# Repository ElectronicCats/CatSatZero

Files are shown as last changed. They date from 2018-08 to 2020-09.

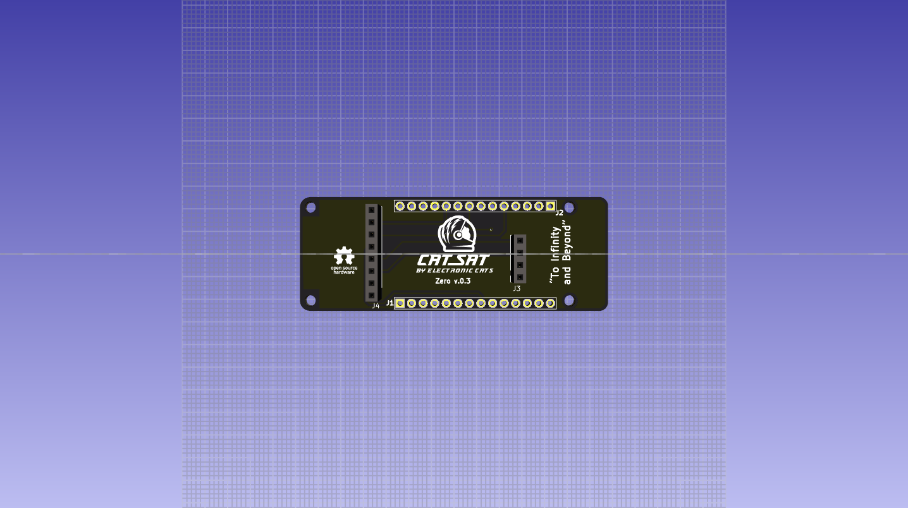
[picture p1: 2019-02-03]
CatSatShield/front.png

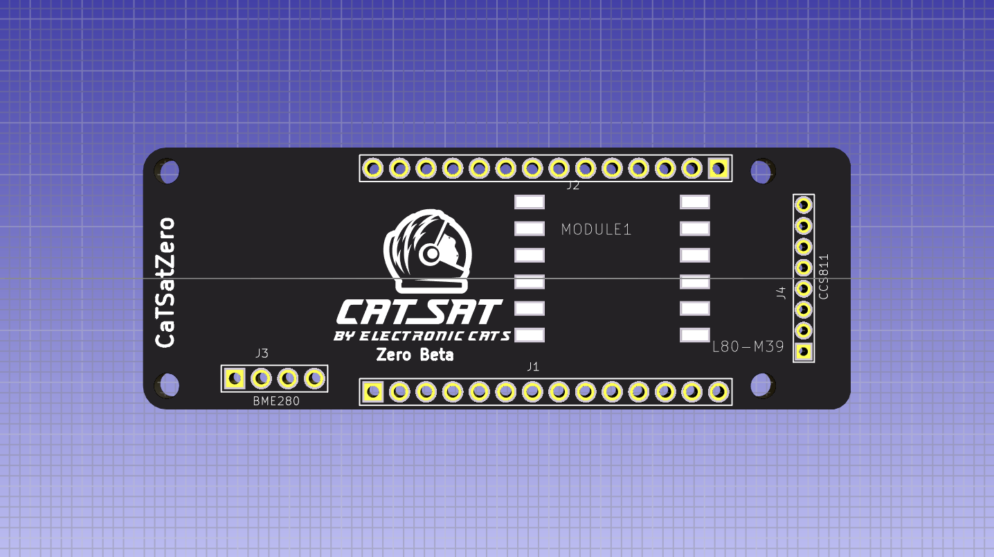
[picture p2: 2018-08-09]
CatSatShield/catsatzero.png

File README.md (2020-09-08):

# CaTSatZero

Kit CatSat Zero Education

Manual and more information in our [Wiki](https://github.com/ElectronicCats/CatSatZero/wiki)

Electronic Cats invests time and resources providing this open source design, please support Electronic Cats and open-source hardware by purchasing products from Electronic Cats!

Designed by Electronic Cats.

<a href="https://electroniccats.com">
  
</a>

## License

OpenSourceLicense

Firmware released under an GNU AGPL v3.0 license. See the LICENSE file for more information.

Hardware released under an CERN Open Hardware Licence v1.2. See the LICENSE_HARDWARE file for more information.

Electronic Cats is a registered trademark, please do not use if you sell these PCBs.

15 April 2018

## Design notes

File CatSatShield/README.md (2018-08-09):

# MKR Shield Template

Template of shield family MKR Arduino in KiCad 5

Mkrshield

Electronic Cats invests time and resources providing this open source design, please support Electronic Cats and open-source hardware by purchasing products from Electronic Cats!

Designed by Electronic Cats.

Hardware released under an CERN Open Hardware Licence v1.2. See the LICENSE_HARDWARE file for more information.

Electronic Cats is a registered trademark, please do not use if you sell these PCBs.

July 2018

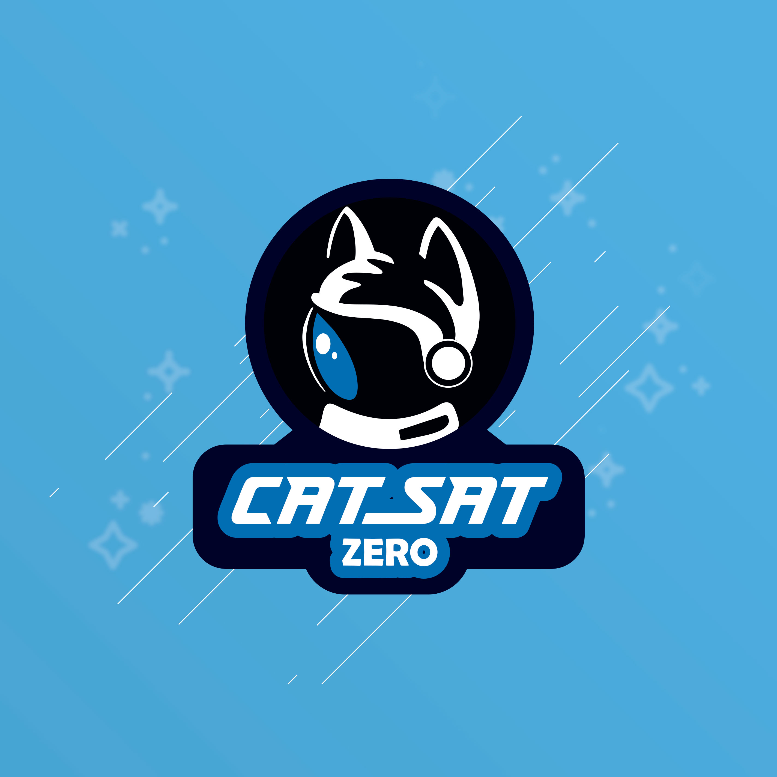
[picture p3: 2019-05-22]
catsatzero.jpg

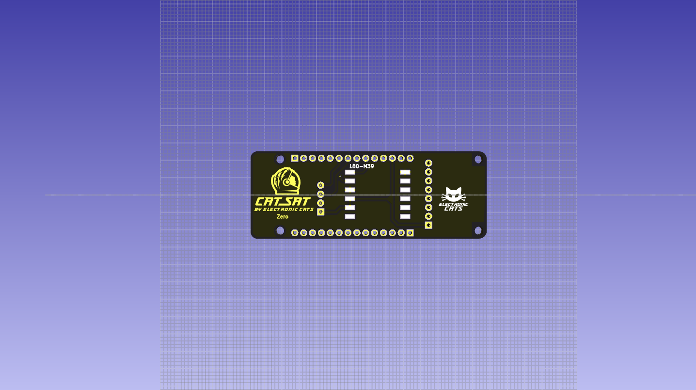
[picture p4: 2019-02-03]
CatSatShield/back.png

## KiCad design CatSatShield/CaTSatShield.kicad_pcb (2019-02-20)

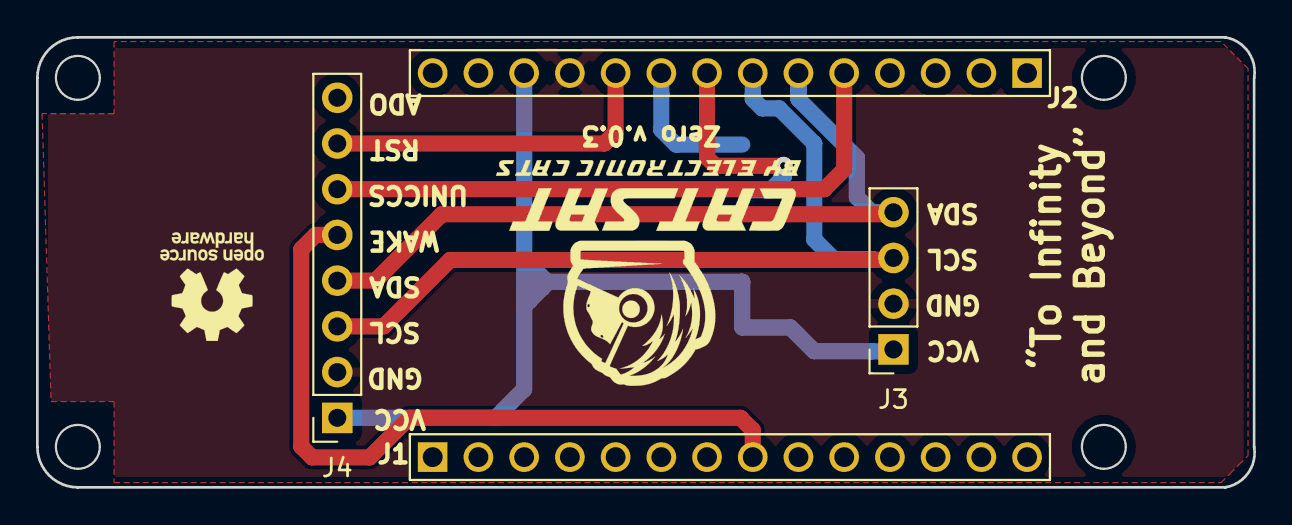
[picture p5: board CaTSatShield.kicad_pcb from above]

Board: 2 copper layers, 67.6 x 25.0 mm, 14 parts (0 on the bottom side), 9 nets.

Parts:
@HOLE0, @HOLE1, @HOLE2, @HOLE3: (no value)
FRAME1: Page 1; FRAME
J1, J2: 61301411121
J3: BME280; PinSocket_1x04_P2.54mm_Vertical
J4: CCS811; PinSocket_1x08_P2.54mm_Vertical
MODULE1: L80-M39; QUECTEL_L80-M39
U$5, U$6, U$7, U$8: MH_RND_F_2.2MM_NM

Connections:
+3V3: J2.12, J3.1, J4.1, MODULE1.4, MODULE1.5
/10-INTCCS: J2.5, J4.6
/RESET: J2.10, J4.7
/RX: J2.8, MODULE1.2
/SCL: J2.7, J3.3, J4.3
/SDA: J2.6, J3.4, J4.4
/TX: J2.9, MODULE1.1
/WAKEA6: J1.8, J4.5
GND: J2.11, J3.2, J4.2, MODULE1.3, MODULE1.12

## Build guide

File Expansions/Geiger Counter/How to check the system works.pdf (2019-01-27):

### How to check the system works

step1）Power on the system, use the USB cable connect the system to computer USB Port
step 2）you could hear the beep and see the led flash
how the Geiger Muller Tube works：

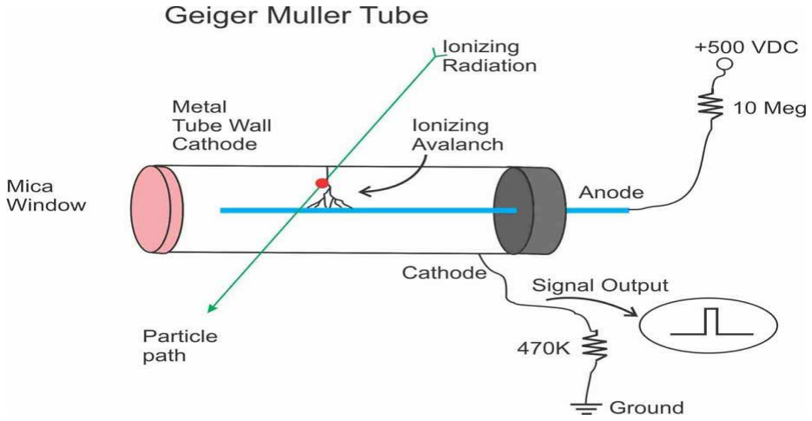
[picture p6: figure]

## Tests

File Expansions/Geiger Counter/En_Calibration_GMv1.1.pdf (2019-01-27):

Calibration:
(the board is calibrated before shipping. If you want to calibrate it again please follow the instruction of calibration)
You need to calibrate the high voltage BEFORE installing Geiger tubes. The HV calibration steps are:
1. Trim R100 potentiometer to approximately 50 ohm when kit power is off.
2. Connect positive Tube Clip to pins (J4) with a jumper wrie.
3. Connect multimeter black probe to any GND point
4. Connect multimeter probe after J2 point

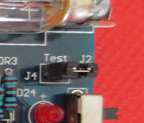
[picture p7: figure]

5. Set your multimeter on 200V DC range.
6. Power up the device (PCB washed and IC555 installed).
7. Adjust voltage with R100 to 6.5V if you use 1M multimeter or adjust the voltage 57V if you use 10M multimeter .Use formula:Vout=Vread*((60M+Rvoltmeter)/Rvoltmeter.)
R100 is the 100Ohm potentiometer.

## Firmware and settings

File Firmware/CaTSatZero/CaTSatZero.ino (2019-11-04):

/************************************************************
  SPANISH
  CatSat Zero
  CatSat Zero - Satelite en Lata Educativo
  Andres Sabas @ Electronic Cats
  Eduardo Contreras @ Electronic Cats
  Original Creation Date: Ago 14, 2018
  https://github.com/ElectronicsCats/CatSatZero/

  Este ejemplos demuestra el funcionamiento basico de los sensores y funcionalidad
  basica del CatSatZero Kit Educativo
  http://electroniccats.com

  Especificaciones del entorno de Desarrollo:
  IDE: Arduino 1.8.4
  Plataforma de Hardware:
  Kit CanSat
  - Arduino MKR1300
  - BMP280
  - CCS811
  - GPS L80


  Este código es beerware si tu me ves ( o cualquier otro miembro de Electronic Cats)
  a nivel local, y tu has encontrado nuestro código útil ,
  por favor comprar una ronda de cervezas!

  Distribuido como; no se da ninguna garantía.
************************************************************/

/************************************************************
  ENGLISH
  CatSat Zero
  CatSat - Satelite en Lata Educativo
  Andres Sabas @ Electronic Cats
  Eduardo Contreras @ Electronic Cats
  Original Creation Date: Agu 14, 2018
  https://github.com/ElectronicsCats/CatSatZero/

  This example demonstrates how to use CatSat

  Development environment specifics:
  IDE: Arduino 1.8.4
  Hardware Platform:
  Kit CanSat
  - Arduino MKR 1300
  - BMP280
  - CCS811
  - GPS L80

  This code is beerware; if you see me (or any other Electronic Cats
  member) at the local, and you've found our code helpful,
  please buy us a round!

  Distributed as-is; no warranty is given.

  Library Arduino LoRa
  https://github.com/sandeepmistry/arduino-LoRa

*/
//Uncomment for debug
//#define DEBUG
//#define DEBUG2

#include <SPI.h>
#include <LoRa.h>

#include <NMEAGPS.h>

#include <Wire.h>
#include <SparkFunBME280.h>

#include <Adafruit_CCS811.h>

#ifdef GEIGER
#define LOG_PERIOD 15000  //Logging period in milliseconds, recommended value 15000-60000.
#define MAX_PERIOD 60000  //Maximum logging period without modifying this sketch

#define index_conversion 151.00

unsigned long counts = 0;     //variable for GM Tube events
unsigned long cpm = 0;        //variable for CPM
unsigned int multiplier;  //variable for calculation CPM in this sketch
unsigned long previousMillis;  //variable for time measurement
float radiationValue = 0.0;

#define radationpin 4

#endif

#define CCS811_ADDR 0x5A //0x5B Alternate I2C Address

//Command activation Balloon mode
#define PMTK_SET_NMEA_886_PMTK_FR_MODE  "$PMTK886,3*2B"
// Command turn on GPRMC and GGA
#define PMTK_SET_NMEA_OUTPUT_RMCGGA "$PMTK314,0,1,0,1,0,0,0,0,0,0,0,0,0,0,0,0,0,0,0*28"

//Global sensor objects
Adafruit_CCS811 ccs;
BME280 myBME280;

static NMEAGPS gps;
static gps_fix  fix;
static uint32_t last_rx = 0UL; // The last millis() time a character was
// received from GPS.

String Todo; //String a mandar

/************************************************************
     IMPORTANTE CAMBIAR id_node DEPENDIENDO TU CANSAT
************************************************************/

String id_node = "A1";

/*******************************************************
  Selecciona un canal entre 0 y 12 este debe coincidir
  con el canal de tu satelite
 *******************************************************/
int channel = 12;

float voltage = 0;

void enviarInfo(String outgoing) {
  LoRa.beginPacket();
  char outgoingCh[Todo.length()+1];
  outgoing.toCharArray(outgoingCh,outgoing.length());
  LoRa.write((uint8_t *)outgoingCh,outgoing.length());                                     
  LoRa.endPacket();                    

#ifdef DEBUG
  SerialUSB.println("Dato enviado");
#endif
}

void gpsread(void) {
  if (fix.valid.location)
  {
    Todo += String(fix.latitude(), 6);
    Todo += ",";
    Todo += String(fix.longitude(), 6);
#ifdef DEBUG 
    SerialUSB.print("Location: ");
    SerialUSB.print(fix.latitude(), 6);
    SerialUSB.print(F(","));
    SerialUSB.print(fix.longitude(), 6);
#endif
  }
  else
  {
    Todo += "0";
    Todo += ",";
    Todo += "0";
#ifdef DEBUG
    SerialUSB.print("INVALID");
#endif
  }
#ifdef DEBUG
  SerialUSB.print("  Date/Time: ");
  if (fix.valid.date)
  {
    SerialUSB.print(fix.dateTime.month);
    SerialUSB.print("/");
    SerialUSB.print(fix.dateTime.day);
    SerialUSB.print("/");
    SerialUSB.print(fix.dateTime.year);
    SerialUSB.print(" ");
  }
  else
  {
    SerialUSB.print("INVALID ");
  }

  SerialUSB.print("");
  if (fix.valid.date)
  {
    if (fix.dateTime.hours < 10) SerialUSB.print("0");
    SerialUSB.print(fix.dateTime.hours);
    SerialUSB.print(":");
    if (fix.dateTime.minutes < 10) SerialUSB.print("0");
    SerialUSB.print(fix.dateTime.minutes);
    SerialUSB.print(":");
    if (fix.dateTime.seconds < 10) SerialUSB.print("0");
    SerialUSB.print(fix.dateTime.seconds);
    SerialUSB.print(".");
  }
  else
  {
    SerialUSB.print("INVALID ");
  }
  SerialUSB.println();
#endif

}

/*
  Activation Balloon mode:
  For high-altitude balloon purpose that the vertical movement will
  have more effect on the position calculation
*/
void ballonModeGPS() {
    if ((Serial1.available())) {
      Serial1.println(PMTK_SET_NMEA_886_PMTK_FR_MODE);
      delay(100);
      Serial1.println(PMTK_SET_NMEA_OUTPUT_RMCGGA);
      SerialUSB.println("GPS balloon mode configured");
    }
    else{
      SerialUSB.println("Error in GPS, balloon mode not configured");
      }
}

void setup() {
  SerialUSB.begin(9600);
  Serial1.begin(9600);
#ifdef DEBUG2
  while (!SerialUSB);
#endif
  SerialUSB.println();
  SerialUSB.println("Settings...");

  pinMode(LED_BUILTIN, OUTPUT);
  digitalWrite(LED_BUILTIN, LOW);

  pinMode(A6, OUTPUT); //Wakeup pin CCS811
  digitalWrite(A6, LOW); //Enable CCS811

  analogReadResolution(10);
  analogReference(AR_INTERNAL2V23); 
  
  /*****LoRa init****/
  if (!LoRa.begin(selectBand(channel))) {           
    Serial.println("LoRa init failed. Check your connections.");
    while (true);                       
  }
  LoRa.enableCrc();
  LoRa.setTxPower(20); //Set the max transmition power
  LoRa.setSpreadingFactor(10); //Change the SF to get longer distances

  /******************/

  //This begins the CCS811 sensor and prints error status of .begin()
  if (!ccs.begin(CCS811_ADDR)) {
    Serial.println("Failed to start sensor CCS811! Please check your wiring.");
    while (1);
  }
 
  Serial.println("CCS begin");
  //calibrate temperature sensor
  while (!ccs.available());
  float temp = ccs.calculateTemperature();
  ccs.setTempOffset(temp - 25.0);

  //For I2C, enable the following and disable the SPI section
  myBME280.settings.commInterface = I2C_MODE;
  myBME280.settings.I2CAddress = 0x76;

  //Initialize BME280
  //For I2C, enable the following and disable the SPI section
  myBME280.settings.commInterface = I2C_MODE;
  myBME280.settings.I2CAddress = 0x76;
  myBME280.settings.runMode = 3; //Normal mode
  myBME280.settings.tStandby = 0;
  myBME280.settings.filter = 4;
  myBME280.settings.tempOverSample = 5;
  myBME280.settings.pressOverSample = 5;
  myBME280.settings.humidOverSample = 5;

  //Calling .begin() causes the settings to be loaded
  delay(10);  //Make sure sensor had enough time to turn on. BME280 requires 2ms to start up.
  int status280 = myBME280.begin();
  
  Serial.println("BME begin");
  if (status280 != 0x60) {
    Serial.println("Could not find a valid BME280 sensor, check wiring!");
    while (1);
  }
  
  ballonModeGPS();
  
#ifdef GEIGER
  multiplier = MAX_PERIOD / LOG_PERIOD;      //calculating multiplier, depend on your log period
  attachInterrupt(digitalPinToInterrupt(radationpin), tube_impulse, FALLING); //define external interrupts
#endif

  SerialUSB.println("CaTSat Zero Ready!");
  Serial.println(F("Fw version 0.0.3"));
}

void loop() {

  Todo += id_node;  //Add id to String
  Todo += ",";

#ifdef GEIGER
  //Read Geiger Sensor
  if (millis() - previousMillis > LOG_PERIOD) {
    previousMillis = millis();
    cpm = counts * multiplier;
    radiationValue = cpm / index_conversion;
#ifdef DEBUG
    Serial.print("cpm = ");
    Serial.println(cpm, DEC);
    Serial.print("uSv/h = ");
    Serial.println(radiationValue, 4);
#endif
    counts = 0;
  }
#endif

  while (gps.available( Serial1 )) {
    last_rx = millis();
    fix = gps.read();

    printInfoSerial();

    // read the input on analog pin battery
    //NOTE: voltage max 1.18v in the pin of chip
    uint16_t sensorValue = analogRead(ADC_BATTERY);
    voltage = sensorValue*2.23/1024;
    voltage = voltage*3.05;

    gpsread();

    Serial.println(Todo);
    enviarInfo(Todo);
    for (int i = 0; i < 5; i++) {
      digitalWrite(LED_BUILTIN, HIGH);
      delay(500);
      digitalWrite(LED_BUILTIN, LOW);
      delay(500);
    }
  }

  Todo = "";
  listenForSomething();
}

void printInfoSerial()
{
  if (ccs.available()) {
    float temp = ccs.calculateTemperature();
    if (!ccs.readData()) {
#ifdef DEBUG
      Serial.print("CO2: ");
      Serial.print(ccs.geteCO2());
      Serial.print("ppm, TVOC: ");
      Serial.print(ccs.getTVOC());
#endif
      Todo += ccs.geteCO2();
      Todo += ",";
      Todo += ccs.getTVOC();
      Todo += ",";
    }
    else {
      Serial.println("ERROR!");
      while (1);
    }
  }

#ifdef DEBUG
  SerialUSB.println();
  SerialUSB.println("BME280 data:");
  SerialUSB.print(" Temperature: ");
  SerialUSB.print(myBME280.readTempC(), 2);
  SerialUSB.println(" degrees C");
#endif
  Todo += myBME280.readTempC();
  Todo += ",";

#ifdef DEBUG
  SerialUSB.print(" Pressure: ");
  SerialUSB.print(myBME280.readFloatPressure(), 2);
  SerialUSB.println(" Pa");
#endif
  Todo += myBME280.readFloatPressure();
  Todo += ",";

#ifdef DEBUG
  SerialUSB.print(" Altitude: ");
  SerialUSB.print(myBME280.readFloatAltitudeMeters(), 2);
  SerialUSB.println("m");
#endif
  Todo += myBME280.readFloatAltitudeMeters();
  Todo += ",";

#ifdef DEBUG
  SerialUSB.print(" %RH: ");
  SerialUSB.print(myBME280.readFloatHumidity(), 2);
  SerialUSB.println(" %");
#endif
  Todo += myBME280.readFloatHumidity();
  Todo += ",";

  // print out the value you read:
#ifdef DEBUG
  Serial.print(voltage);
  Serial.println(" V");
#endif
  Todo += voltage;
  Todo += ",";

  SerialUSB.println();
}

long selectBand(int a) {
  switch (a) {
    case 0:
      return 903080000; //903.08Mhz
      break;
    case 1:
      return 905240000; //905.24
      break;
    case 2:
      return 907400000; //907.40
      break;
    case 3:
      return 909560000; //909.56
      break;
    case 4:
      return 911720000; //911.72
      break;
    case 5:
      return 913880000; //913.88
      break;
    case 6:
      return 916040000; //916.04
      break;
    case 7:
      return 918200000; // 918.20
      break;
    case 8:
      return 920360000; //920.36
      break;
    case 9:
      return 922520000; //922.52
      break;
    case 10:
      return 924680000; //924.68
      break;
    case 11:
      return 926840000; //926.84
      break;
    case 12:
      return 915000000; //915
      break;
  }
}

//----------------------------------------------------------------
//  Listen to see if the GPS device is correctly
//  connected and functioning.

static void listenForSomething(){
  uint32_t current_ms  =  millis();
  uint32_t ms_since_last_rx   = current_ms - last_rx;
  if ((ms_since_last_rx > 7000)) {
    Serial1.println( F("\nCheck GPS device and/or connections.  No data received.\n") );
  }
}

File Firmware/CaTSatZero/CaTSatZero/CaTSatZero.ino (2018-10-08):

/************************************************************
SPANISH
CatSat Zero
CatSat Zero - Satelite en Lata Educativo
Andres Sabas @ Electronic Cats
Eduardo Contreras @ Electronic Cats
Original Creation Date: Ago 14, 2018
https://github.com/ElectronicsCats/CatSatZero/

Este ejemplos demuestra el funcionamiento basico de los sensores y funcionalidad
basica del CatSatZero Kit Educativo
http://electroniccats.com

Especificaciones del entorno de Desarrollo:
  IDE: Arduino 1.8.4
  Plataforma de Hardware:
  Kit CanSat
  - Arduino MKR1300
  - BMP280
  - CCS811
  - GPS L80


Este código es beerware si tu me ves ( o cualquier otro miembro de Electronic Cats) 
a nivel local, y tu has encontrado nuestro código útil ,
por favor comprar una ronda de cervezas!

Distribuido como; no se da ninguna garantía.
************************************************************/

/************************************************************
ENGLISH
CatSat Zero
CatSat - Satelite en Lata Educativo
Andres Sabas @ Electronic Cats
Eduardo Contreras @ Electronic Cats
Original Creation Date: Agu 14, 2018
https://github.com/ElectronicsCats/CatSatZero/

This example demonstrates how to use CatSat

Development environment specifics:
  IDE: Arduino 1.8.4
  Hardware Platform:
  Kit CanSat
  - Arduino MKR 1300
  - BMP280
  - CCS811
  - GPS L80

This code is beerware; if you see me (or any other Electronic Cats 
member) at the local, and you've found our code helpful, 
please buy us a round!

Distributed as-is; no warranty is given.

Library TinyGPS++
https://github.com/mikalhart/TinyGPSPlus

Library Arduino LoRa
https://github.com/sandeepmistry/arduino-LoRa

*/

#include <SPI.h>
#include <LoRa.h>

#include <TinyGPS++.h>

#include <Wire.h>
#include <SparkFunBME280.h>
#include <SparkFunCCS811.h>

#define PIN_NOT_WAKE 5

#define CCS811_ADDR 0x5A //Alternate I2C Address

//Command activation Balloon mode
#define PMTK_SET_NMEA_886_PMTK_FR_MODE  "$PMTK001,886,3*36"

//Global sensor objects
CCS811 myCCS811(CCS811_ADDR);
BME280 myBME280;

TinyGPSPlus gps;
int gps_flag = 0;

String Todo; //String a mandar

/************************************************************
*    IMPORTANTE CAMBIAR id_node DEPENDIENDO TU CANSAT      *
************************************************************/

String id_node= "A1"; 

/*******************************************************  
 *Selecciona un canal entre 0 y 12 este debe coincidir *
 *con el canal de tu satelite                          *
 *******************************************************/
int channel = 12;  

byte msgCount = 0;            // count of outgoing messages
byte localAddress = 0xBB;     // address of this device
byte destination = 0xFF;      // destination to send to

float voltage=0;

void enviarInfo(String outgoing) {
  LoRa.beginPacket();                   // start packet
  LoRa.write(destination);              // add destination address
  LoRa.write(localAddress);             // add sender address
  LoRa.write(msgCount);                 // add message ID
  LoRa.write(outgoing.length());        // add payload length
  LoRa.print(outgoing);                 // add payload
  LoRa.endPacket();                     // finish packet and send it
  msgCount++;                           // increment message ID
  SerialUSB.println("Dato enviado");
}

void onReceive(int packetSize) {
  if (packetSize == 0) return;          // if there's no packet, return

  // read packet header bytes:
  int recipient = LoRa.read();          // recipient address
  byte sender = LoRa.read();            // sender address
  byte incomingMsgId = LoRa.read();     // incoming msg ID
  byte incomingLength = LoRa.read();    // incoming msg length

  String incoming = "";

  while (LoRa.available()) {
    incoming += (char)LoRa.read();
  }

  if (incomingLength != incoming.length()) {   // check length for error
    Serial.println("error: message length does not match length");
    return;                             // skip rest of function
  }

  // if the recipient isn't this device or broadcast,
  if (recipient != localAddress && recipient != 0xFF) {
    Serial.println("This message is not for me.");
    return;                             // skip rest of function
  }

  // if message is for this device, or broadcast, print details:
  Serial.println("Received from: 0x" + String(sender, HEX));
  Serial.println("Sent to: 0x" + String(recipient, HEX));
  Serial.println("Message ID: " + String(incomingMsgId));
  Serial.println("Message length: " + String(incomingLength));
  Serial.println("Message: " + incoming);
  Serial.println("RSSI: " + String(LoRa.packetRssi()));
  Serial.println("Snr: " + String(LoRa.packetSnr()));
  Serial.println();
}

void gpsread(void){
  
  // 
  while ((Serial1.available() > 0) && (gps_flag == 0))
    if (gps.encode(Serial1.read()))
    {
     SerialUSB.print(F("Location: ")); 
      if (gps.location.isValid())
      { 
        Todo += String(gps.location.lat(), 6);
        Todo += ",";
        Todo += String(gps.location.lng(), 6);
        Todo += "\n";
        SerialUSB.print(gps.location.lat(), 6);
        SerialUSB.print(F(","));
        SerialUSB.print(gps.location.lng(), 6);
        gps_flag = 1;
      }
      else
      { 
        Todo += "0";
        Todo += ",";
        Todo += "0";
        Todo += "\n";
        SerialUSB.print(F("INVALID"));
        gps_flag = 1;
      }

      SerialUSB.print(F("  Date/Time: "));
      if (gps.date.isValid())
      {
        SerialUSB.print(gps.date.month());
        SerialUSB.print(F("/"));
        SerialUSB.print(gps.date.day());
        SerialUSB.print(F("/"));
        SerialUSB.print(gps.date.year());
      }
      else
      {
        SerialUSB.print(F("INVALID"));
      }

      SerialUSB.print(F(""));
      if (gps.time.isValid())
      {
        if (gps.time.hour() < 10) SerialUSB.print(F("0"));
        SerialUSB.print(gps.time.hour());
        SerialUSB.print(F(":"));
      if (gps.time.minute() < 10) SerialUSB.print(F("0"));
        SerialUSB.print(gps.time.minute());
        SerialUSB.print(F(":"));
      if (gps.time.second() < 10) SerialUSB.print(F("0"));
        SerialUSB.print(gps.time.second());
        SerialUSB.print(F("."));
      if (gps.time.centisecond() < 10) SerialUSB.print(F("0"));
        SerialUSB.print(gps.time.centisecond());
      }
      else
      {
        SerialUSB.print(F("INVALID"));
      }

      SerialUSB.println(); 
     }
      

      if (millis() > 5000 && gps.charsProcessed() < 10)
      {
        SerialUSB.println(F("No GPS detected: check wiring."));
        while(true);
      }
  
}
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

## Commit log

2018-04-15 Schematic Alfa
    [MainBoard.kicad_pcb, MainBoard.sch]
2018-04-17 Add library kicad
2018-04-17 Fix schematic libraries
    [MainBoard.sch]
2018-04-17 check button
    [MainBoard.sch]
2018-04-17 Clean PCB
    [MainBoard.kicad_pcb]
2018-04-17 Shottcky diode fix
    [MainBoard.sch]
2018-04-27 Assign footprints
    [MainBoard.sch]
2018-05-14 Update netlist
    [MainBoard.sch]
2018-05-14 Update PCB battery Hole
    [MainBoard.kicad_pcb]
2018-08-01 Update for MakeCode
    [MainBoard.kicad_pcb, MainBoard.sch]
2018-08-09 Move project to MKR1300 shield
    Change Board base
    [CaTSatShield.kicad_pcb, CaTSatShield.sch, MainBoard.kicad_pcb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]
2018-08-10 Best logos
    [CaTSatShield.kicad_pcb]
2018-08-14 Update logos
    [CaTSatShield.kicad_pcb]
2018-08-14 Init firmware CatSatZero sensor BMP280 and CCS811
2018-08-21 Fix TX and RX Serial with GPS
    [CaTSatShield.sch]
2018-08-21 Remove extra layers
    [CaTSatShield.kicad_pcb]
2018-08-21 Update version 0.2-beta
    Fix Tx and RX, add logo OSHW
    [CaTSatShield.kicad_pcb]
2018-08-21 settings for gerbers
    [CaTSatShield.kicad_pcb]
2018-10-02 Fix voltage line
    [CaTSatShield.sch]
2018-10-02 change connector header x socker J4
    [CaTSatShield.kicad_pcb]
2018-10-02 routeo change voltage
    [CaTSatShield.kicad_pcb, _saved_CaTSatShield.sch]
2018-10-03 connected pin wakeA6
    [CaTSatShield.kicad_pcb]
2018-10-03 Label wakeA6 sch
    [CaTSatShield.sch, _saved_CaTSatShield.sch]
2018-10-04 Added voltage battery
2018-10-31 Add led blink for send
2018-10-31 Conversion battery to %
2018-11-01 update to version 0.3
    Update silks
    [CaTSatShield.kicad_pcb]
2018-11-01 Change pin names
2018-11-05 commentary for CCS811 pin enable
2018-11-05 Fix temporal for GPS not data
    [CaTSatZero.ino]
2018-11-22 configure gerbers
    [CaTSatShield.kicad_pcb]
2019-01-17 define pins for other boards
2019-01-18 fix typo in serial GPS command
    [CaTSatZero.ino]
2019-01-18 best format print GPS data
2019-01-25 fix GPS without gps flag
    [CaTSatZero.ino]
2019-01-27 add documentation geiger sensor
2019-01-27 best comment for pin ccs811
2019-02-03 add altitude and velocity GPS
2019-02-03 fix remove extra value
    [CaTSatZero.ino]
2019-02-08 best detect error in CCS811
    [CaTSatZero.ino]
2019-02-08 remove data sensor not used
2019-02-11 track width
    [CaTSatShield.kicad_pcb]
2019-02-14 pin name
    [CaTSatShield.kicad_pcb]
2019-02-26 Add GPS balloon mode
    Change voltage reference
2019-02-26 Add check wiring GPS
2019-03-02 fix if ballon configured
    [CaTSatZero.ino]
2019-03-04 Fiz battery level measurement
2019-07-26 Test write function instead of print
